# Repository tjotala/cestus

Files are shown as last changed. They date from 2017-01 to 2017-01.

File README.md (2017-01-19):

# Cestus

## Introduction

This is a software & hardware project for an automatic orientation-controlled turn & stop light mounted on bicycle gloves. Hence, the name [___cestus___](https://en.wikipedia.org/wiki/Cestus): the Latin word for a ___battle glove___ used by boxers and gladiators of ancient Greece and Rome. Seems appropriate, given how dangerous it can be to share the road in the U.S.

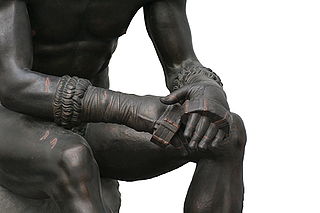
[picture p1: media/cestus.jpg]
cestus


## Hardware Parts

| Part | Cost |
| ---- | ---: |
| [Adafruit Flora v3](https://www.adafruit.com/product/659) system board | $14.95 |
| [Adafruit LSM9DS0](https://www.adafruit.com/products/2020) sensor board | $19.95 |
| [Adafruit NeoPixel Ring 16](https://www.adafruit.com/products/1463) multicolor LEDs | $9.95 |
| [Adafruit LiPoly 150mAh Battery](https://www.adafruit.com/products/1317) | $5.95 |
| **TOTAL** | **$50.80** |

In addition, you'll need a bicycle glove (or really any glove) and some [1&frac12;" diameter clear heat shrink tubing](http://www.frys.com/product/3222541). When flattened, the heat shrink tubing is about 2" wide and fits nicely around the Flora board stacked with the NeoPixel ring.

Note that these only make up one __cestus__ glove. If you build two, they operate independently of each other. While this is perhaps not the most cost-effective option, it wasn't a huge concern for me.

Some alternatives to consider for a more cost-effective solution:

* I used the Adafruit Flora system board even though a less powerful (and smaller) system board would suffice: for example, [Adafruit Gemma v2](https://www.adafruit.com/product/1222). The challenge is that doing so would require substantial re-factoring of the stock Adafruit libraries, in particular trading off flexibility and portability in favor of reduced code size. Gemma has only about 5KB of code space, and the project as currently written compiles to about 15.5KB (Flora has about 28.5KB available). Additionally, Gemma (based on ATtiny85) is not officially supported by the [LSM9DS0 sensor library](https://github.com/adafruit/Adafruit_LSM9DS0_Library) though I believe it ought to work.
* I used the Adafruit LSM9DS0 sensor board even though it was a complete overkill as I really only needed the accelerometer for this project. You could use one of the cheaper sensors with less features: for example, [Adafruit LSM303](https://www.adafruit.com/products/1247) or [Adafruit LIS3DH](https://www.adafruit.com/products/2809).

## Hardware Assembly

The hardware wiring is pretty straightforward, as illustrated below. You could use another pin instead of `D6` for the NeoPixel ring, but doing so will require changing the `CONF_NEOPIXEL_PIN` constant in the code.

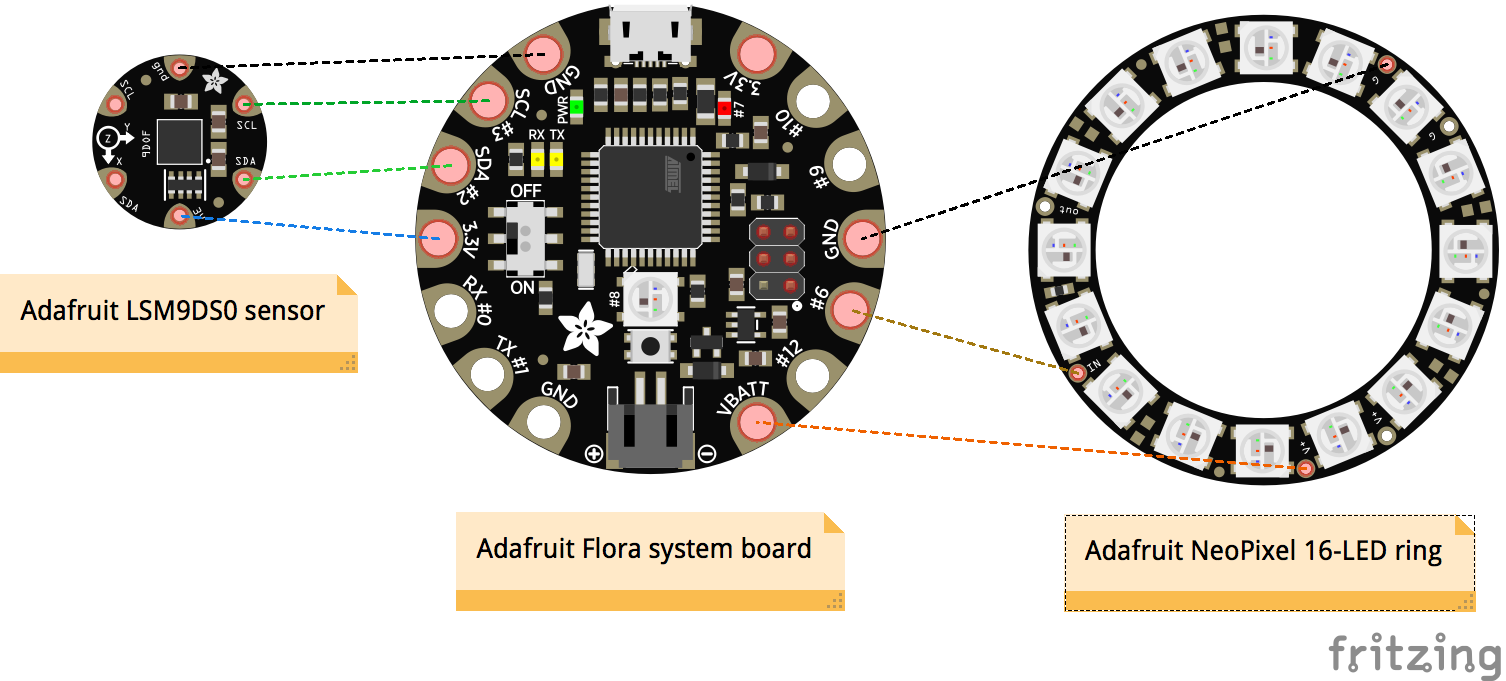
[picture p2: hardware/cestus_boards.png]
Boards


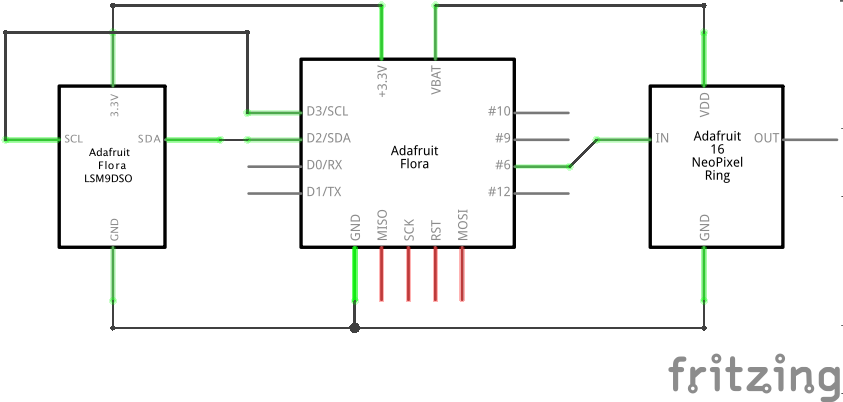
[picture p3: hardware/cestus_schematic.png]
Schematic


## Software Pre-requisites

You will need to install the [Arduino IDE](https://learn.adafruit.com/adafruit-arduino-ide-setup/arduino-1-dot-6-x-ide) or equivalent development environment. In addition, you will need to install the following Arduino libraries:

1. [Adafruit Unified Sensor Library](https://github.com/adafruit/Adafruit_Sensor)
2. [Adafruit LSM9DS0 Sensor Library](https://github.com/adafruit/Adafruit_LSM9DS0_Library)
3. [Adafruit AHRS (Altitude and Heading Reference System) Library](https://github.com/adafruit/Adafruit_AHRS)
4. [Adafruit NeoPixel library](https://github.com/adafruit/Adafruit_NeoPixel)
5. [NeoPatterns library](https://github.com/tjotala/NeoPatterns) which I adapted from the original [Adafruit NeoPatterns](https://learn.adafruit.com/multi-tasking-the-arduino-part-3/using-neopatterns) library to better suit my needs and enable easier enhancements. The original library is not in GitHub, otherwise I would have forked it.

## Building the Software

1. Download the [code](https://github.com/tjotala/Cestus) -or- clone the repo: `git clone https://github.com/tjotala/Cestus.git`
2. Launch the Arduino IDE
3. Open the sketch: `File` -> `Open...`
3. Build the code: `Sketch` -> `Verify/Compile`

## Uploading Code to the Device

1. Connect the device to a free USB port
2. Configure the Arduino IDE for Flora using the `Tools` menu:
   1. Under `Board`, select `Arduino Flora`
   2. Under `Port`, select the appropriate USB port (on a Mac, it is named something like `/dev/cu.usbmodemNNN`)
3. Upload the code: `Sketch` -> `Upload`

## Operation

Once the device is powered ON, it will respond to the following motions from the level orientation - that is, if your gloved hand is flat on a table with the palm down.

1. Tilt the device **sideways** in either direction (i.e. 90&deg; from level), and it will animate a turn signal consisting of a _scanner_ pattern of red LEDs. This is similar to the back-and-forth swoosh of the [Knight Rider car](https://www.youtube.com/watch?v=54O_1mOab4Y), or the [Cylon warrior "eye"](https://www.youtube.com/watch?v=0ccKPSVQcFk) from Battlestar Galactica.
2. Tilt the device **straight up** (i.e. 90&deg; upward from level), and it will animate a stop signal consisting of red LEDs being turned alternatively ON and OFF (apparently known as _theater chase_ pattern).
3. Tilt the device **straight down** (i.e. 90&deg; downward from level), and it will animate a go signal consisting of white LEDs pulsating ON and OFF (I coined the name _pulsar_ pattern).

## Tweaking the Software

1. The `CONF_USE_DEBUG_OUTPUT` and `CONF_DEBUG_OUTPUT_SPEED` constants control whether to send debug output messages to the host Mac/PC over serial connection, and how fast to do it. Turning this OFF (the default) saves couple of KB of code space.
2. The `CONF_BLINK_ONBOARD_LED` constant controls whether to blink the on-board LED each time the code samples the orientation sensor. Given that the LED is on the underside of the device, this is purely for debugging purposes.
3. The `CONF_TURN_xxx` constants control the orientation tolerance, timing, colors, etc. of the turn signal.
4. The `CONF_STOP_xxx` constants control the orientation tolerance, timing, colors, etc. of the stop signal.
5. The `CONF_GO_xxx` constants control the orientation tolerance, timing, colors, etc. of the go signal.
6. The `CONF_ONBOARD_LED_PIN` constant defines which digital pin connects to the on-board LED. On the Flora board, this is always 7.
7. The `CONF_ONBOARD_NEOPIXEL_PIN` constant defines which digital pin connects to the on-board NeoPixel LED. On the Flora board, this is always 8.
8. The `CONF_NEOPIXEL_PIN` constant defines which digital ping connects to the NeoPixel ring, and the `CONF_NEOPIXEL_LEDS` constant defines how many LEDs there are in the NeoPixel ring/strip.

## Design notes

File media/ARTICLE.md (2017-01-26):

# I Have Seen The Light... and It Is Smarter

Something has always bothered me about bicycle lights: they are fundamentally dumb. No, I do not mean that they are useless - but rather how they are not adaptive to our riding behavior. There is no way to indicate intent as we do with the turn signals and brake lights in a car.

## Solution

A while back I decided to solve this problem when I resumed bicycling for exercise. I named the solution [___cestus___](https://en.wikipedia.org/wiki/Cestus), after the Latin word for an armored ___battle glove___ used by boxers and gladiators of ancient Greece and Rome. It seemed only appropriate given how dangerous it can be to share the road in the U.S.

cestus

credit: [wikimedia](https://upload.wikimedia.org/wikipedia/commons/thumb/7/70/Boxer_of_quirinal_hands.jpg/320px-Boxer_of_quirinal_hands.jpg)

The idea is to attach this smarter bicycle light to the back of hand of a regular biking glove, and do what feels fairly natural:

* When I extend my arm to the left or right with the palm facing forward, it animates a red turn signal.
* When I extend my arm straight up, it flashes all the LEDs as a red stop signal.
* When I extend my arm down or simply tilt my wrist down, it turns into a flashing bright white headlight.

The tolerance for those positions is fairly loose, &plusmn;30&deg; from the 90&deg; orientation, to accommodate sloppy signaling.

The videos below illustrate this much better than my words.

### Turn Signal
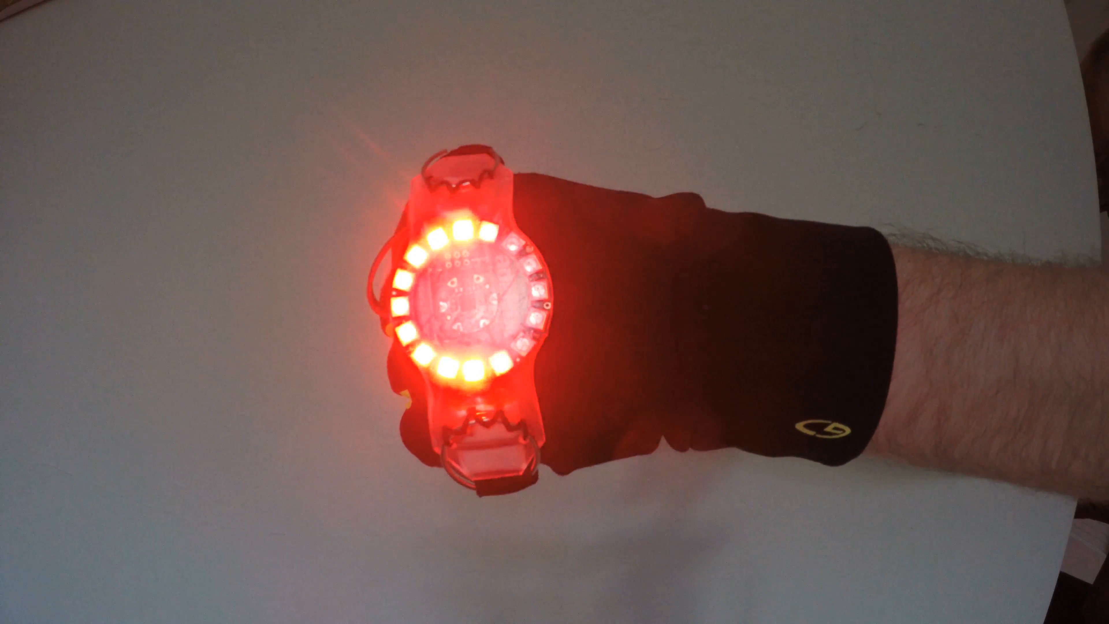
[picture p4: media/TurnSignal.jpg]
Turn Signal


### Stop Signal
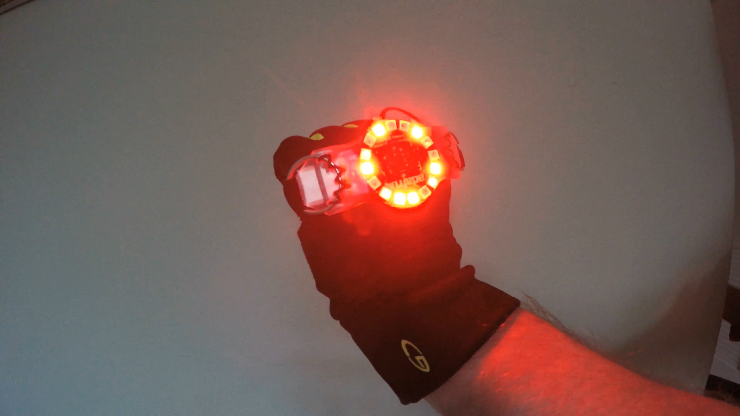
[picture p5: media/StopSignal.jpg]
Stop Signal


### Headlight
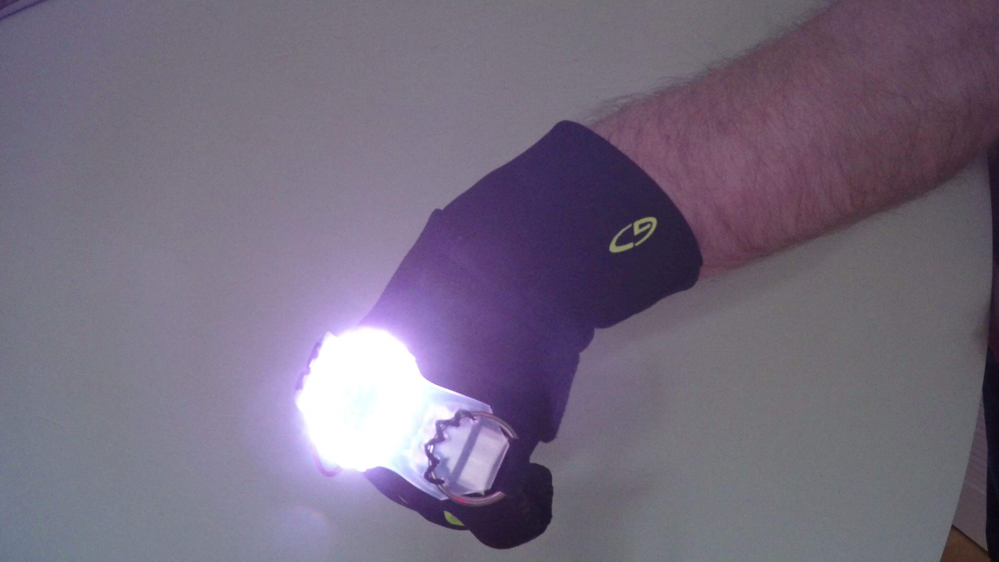
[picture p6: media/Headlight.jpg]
Headlight


## Hardware

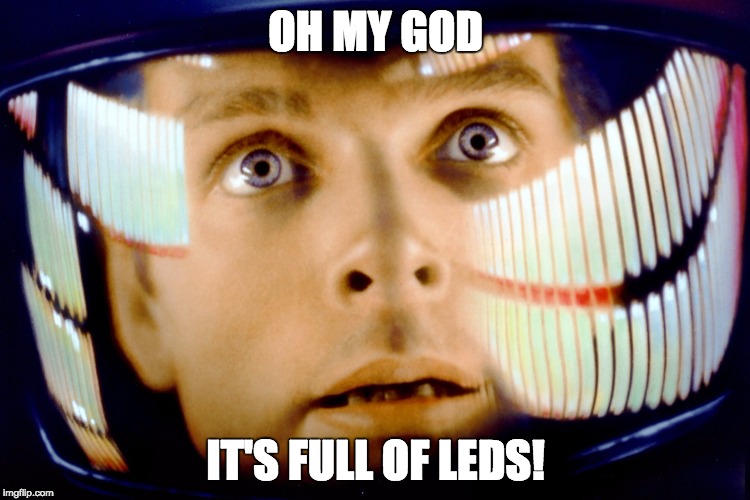
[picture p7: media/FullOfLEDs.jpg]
Full of LEDs


The proof-of-concept system consists of four components developed by [Adafruit] for wearable designs:

1. An [Arduino]-compatible system board
2. A sensor board
3. A highly visible ring of 16 multicolor LEDs
3. A small rechargeable LiPoly battery

The total cost of the parts is around $50, and with one charge of the battery it runs for about 30-60 minutes depending on usage. I could have used a higher capacity battery but my bicycle rides are simply not long enough to justify it.

If I were to productize this solution, I could substantially reduce the cost with less expensive parts and tighter system integration. Unlike it's ancient name sake, I chose not to encase it in armor or leather due to both weight and cost considerations. I thought of 3D printing a case for the light, but ultimately simply wrapped it in clear heat shrink tubing to protect it from the elements. In addition, I chose to mount the device on a neoprene strap that I can then slip over my hand, rather than sew it directly onto the back of the glove. This has the added benefit of being able to use it without a glove, like in the middle of scorching California summer, and makes it easier to wash the gloves.

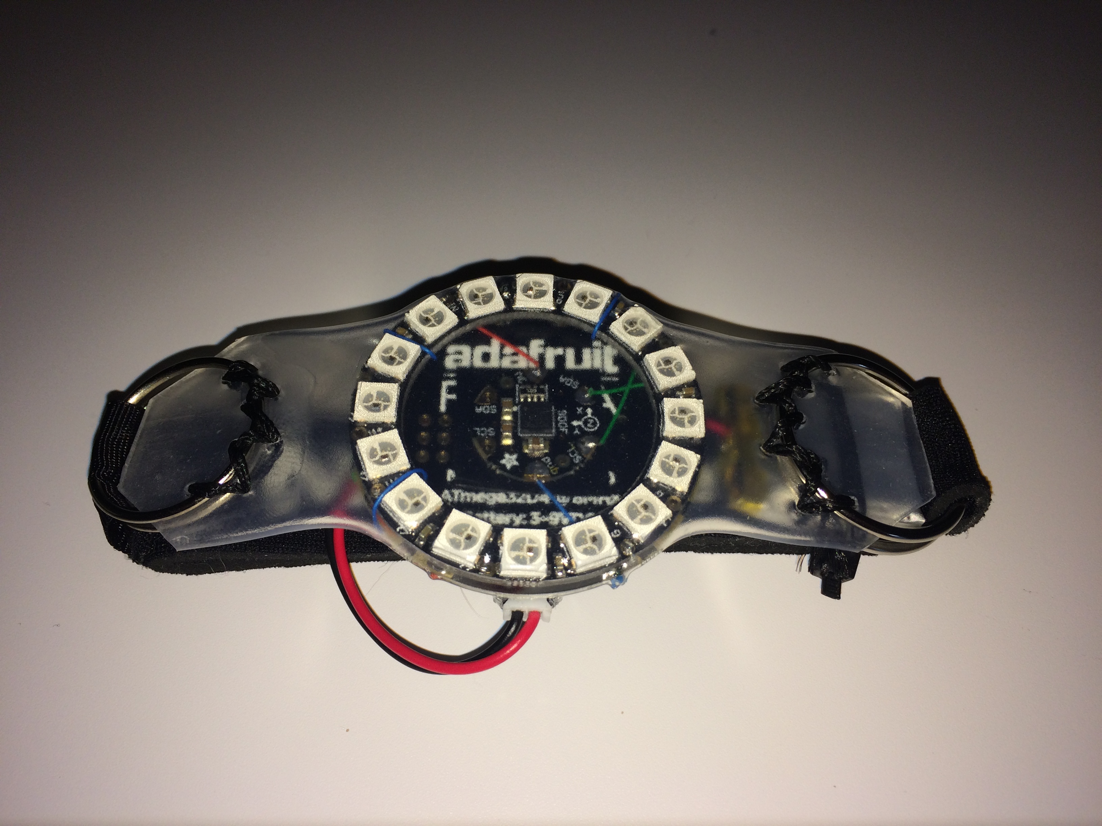
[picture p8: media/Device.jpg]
Device


## Software

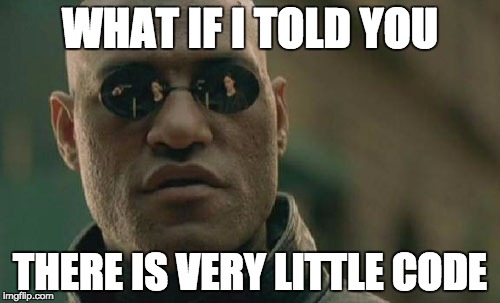
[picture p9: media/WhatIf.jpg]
What If I Told You


The software is very simple: there's only about 100 lines of actual C++ code, aside from existing [Adafruit] libraries. As with any [Arduino] application, there are two functions:

* The `setup` function is called at power on exactly once to initialize everything
* The `loop` function gets called repeatedly until power off. It samples the orientation sensor in the beginning of each iteration, and then switches between four possible states:

	1. Begin animating a new signal
	2. Continue animating a previously chosen signal
	3. Stop animating a signal
	4. Do nothing

## Technical Details

The source code and wiring diagrams are freely available in a [github][repo] repository under MIT license. If you are interested in more technical details, check out the [README][repo].

## Conclusion

This was a fun little project. As usual for me, the software was simple and the toughest part was figuring out how to package the hardware in a way that is easy to use, easy to attach to a glove, and robust enough to handle the harsh California weather. Why, we sometimes even get rain around here!

## Enhancement Ideas

The sensor board I used can also measure acceleration, compass heading and temperature. I only needed the orientation for this project as currently implemented. I was tempted to automatically turn on the stop signal automatically based on sudden deceleration. I thought of making the ring LED briefly show a heading indicator if flicked in a certain way, or perhaps do something cute with the temperature data. I could also make something like interval timer or elapsed time by turning on sections of the LEDs.

Ultimately I decided against all those ideas, because of their limited utility. Without moving your hand, automating the stop signal would not be visible to anyone behind you. As for the compass heading indicator or temperature, I simply did not see much utility in them. I do not bike far enough for the heading to matter, and my skin can readily tell if it is cold or hot. The timer features might come in handy but then most of the time I bike with a smartphone that acts as GPS tracker so I have no need for additional clock sources.

Speaking of GPS, it would be fairly easy to add a GPS receiver to this device as well, but that would substantially increase the cost and power consumption, not to mention create further problems with where to store the location data and how to offload it. In short, it creates more problems than it solves: a classic case of "just because we can, we should not". Put another way, don't draw legs on the snake as the Chinese proverb goes.

[Arduino]: https://www.arduino.cc/
[Adafruit]: https://www.adafruit.com/
[repo]: https://github.com/tjotala/cestus

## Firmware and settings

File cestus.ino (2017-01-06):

//
// Cestus
//
// Copyright (c) 2016-2017 Tapani J. Otala
//
// See README.md for details on the source code.
// See LICENSE for details on license.
//
#include <Adafruit_LSM9DS0.h>
#include <Adafruit_Simple_AHRS.h>
#include <Adafruit_NeoPixel.h>
#include <NeoPatterns.h>

// common colors
#define COLOR(r, g, b)              Adafruit_NeoPixel::Color(r, g, b)
#define COLOR_BLACK                 COLOR(0, 0, 0)
#define COLOR_WHITE                 COLOR(255, 255, 255)
#define COLOR_RED                   COLOR(255, 0, 0)
#define COLOR_GREEN                 COLOR(0, 255, 0)
#define COLOR_BLUE                  COLOR(0, 0, 255)

// brightness setting 0..255 from percentage 0..100%
#define BRIGHTNESS(b)               uint8_t((b) != 0 ? 255 * 100 / (b) : 0) 

// configuration settings
#define CONF_USE_DEBUG_OUTPUT       false         // true: enable, false: disable
#define CONF_DEBUG_OUTPUT_SPEED     115200        // bps

#define CONF_BLINK_ONBOARD_LED      50            // ms; set to 0 to not blink at all

#define CONF_TURN_TOLERANCE         30            // ± degrees; tolerance from 90deg roll (for turn signal)
#define CONF_TURN_INTERVAL          10            // ms
#define CONF_TURN_COLOR             COLOR_RED
#define CONF_TURN_BRIGHTNESS        BRIGHTNESS(50)
#define CONF_TURN_SPLIT             true          // true: split the pattern into two segments, false: unidirectional pattern

#define CONF_STOP_TOLERANCE         30            // ± degrees; tolerance from 90deg pitch (for stop signal)
#define CONF_STOP_INTERVAL          50            // ms
#define CONF_STOP_COLOR1            COLOR_RED
#define CONF_STOP_COLOR2            COLOR_BLACK
#define CONF_STOP_BRIGHTNESS        BRIGHTNESS(100)

#define CONF_GO_TOLERANCE           30            // ± degrees; tolerance from 90deg pitch (for ride signal)
#define CONF_GO_INTERVAL            100           // ms
#define CONF_GO_COLOR1              COLOR_WHITE
#define CONF_GO_COLOR2              COLOR_BLACK
#define CONF_GO_BRIGHTNESS          BRIGHTNESS(100)

// hardware constants for Adafruit Flora on-board resources
#define CONF_ONBOARD_LED_PIN        7             // hardwired
#define CONF_ONBOARD_NEOPIXEL_PIN   8             // hardwired

// hardware constants for the NeoPixel ring
#define CONF_NEOPIXEL_PIN           6             // connected to pin D6
#define CONF_NEOPIXEL_LEDS          16            // number of LEDs

#if CONF_USE_DEBUG_OUTPUT
#define DEBUG_OUT(msg)              Serial.print(msg)
#define DEBUG_OUTLN(msg)            Serial.println(msg)
#else
#define DEBUG_OUT(msg)              /* nothing */
#define DEBUG_OUTLN(msg)            /* nothing */
#endif

//
// Derived Classes
//
class TurnPattern : public Scanner
{
public:
    TurnPattern(NeoPatterns& pixels) : Scanner(pixels, CONF_TURN_INTERVAL, CONF_TURN_COLOR, CONF_TURN_SPLIT) { }
};

class StopPattern : public TheaterChase
{
public:
    StopPattern(NeoPatterns& pixels) : TheaterChase(pixels, CONF_STOP_INTERVAL, CONF_STOP_COLOR1, CONF_STOP_COLOR2) { }
};

class GoPattern : public Pulsar
{
public:
    GoPattern(NeoPatterns& pixels) : Pulsar(pixels, CONF_GO_INTERVAL, CONF_GO_COLOR1, CONF_GO_COLOR2) { }
};

//
// Global Variables
//
NeoPatterns ring(CONF_NEOPIXEL_LEDS, CONF_NEOPIXEL_PIN);
Adafruit_LSM9DS0 sensor;
Adafruit_Simple_AHRS ahrs(&sensor.getAccel(), &sensor.getMag());

//
// Setup function
//
// This executes exactly once, at startup
//
void setup()
{
#if CONF_USE_DEBUG_OUTPUT
    Serial.begin(CONF_DEBUG_OUTPUT_SPEED);
    DEBUG_OUTLN(F("Cestus v1.0"));
#endif

#if CONF_BLINK_ONBOARD_LED
    // initialize the on-board LED
    pinMode(CONF_ONBOARD_LED_PIN, OUTPUT);
#endif

    // initialize the sensor(s)
    // we really only need acceleration
    // however, the AHRS library expects magnetometer as well
    // we do not need the gyroscope or temperature
    sensor.setupAccel(sensor.LSM9DS0_ACCELRANGE_2G);
    sensor.setupMag(sensor.LSM9DS0_MAGGAIN_2GAUSS);
    if (!sensor.begin())
    {
#if CONF_USE_DEBUG_OUTPUT
        while (true)
        {
            DEBUG_OUTLN(F("Oops ... unable to initialize the LSM9DS0. Check your I2C wiring!"));
        }
#endif
    }

    // initialize the NeoPixel Ring
    ring.begin();
}

template<typename T> bool InRange(T val, T min, T max)
{
    return min <= val && val <= max;
}

//
// Loop
//
// This code runs continuously until powered off
//
void loop()
{
#if CONF_BLINK_ONBOARD_LED
    //
    // Blink the on-board LED
    //
    digitalWrite(CONF_ONBOARD_LED_PIN, HIGH);
    delay(CONF_BLINK_ONBOARD_LED);
    digitalWrite(CONF_ONBOARD_LED_PIN, LOW);
#endif
  
    //
    // Sample the current orientation
    //
    sensors_vec_t orientation;
    ahrs.getOrientation(&orientation);

    DEBUG_OUT(F("roll: ")); DEBUG_OUT(int(orientation.roll));
    DEBUG_OUT(F(", pitch: ")); DEBUG_OUT(int(orientation.pitch));
    DEBUG_OUT(F(", heading: ")); DEBUG_OUT(int(orientation.heading));
    DEBUG_OUTLN(F(""));

    //
    // Animate a stop signal if we're oriented at 90deg pitch angle, with ±CONF_STOP_TOLERANCE
    //
    if (InRange(int(orientation.pitch), 90 - CONF_STOP_TOLERANCE, 90 + CONF_STOP_TOLERANCE))
    {
        static StopPattern stop(ring);
        if (!ring.IsActive(&stop))
        {
            DEBUG_OUTLN(F("starting stop animation"));
            ring.setBrightness(CONF_STOP_BRIGHTNESS);
            ring.Start(&stop);
        }
    }
    //
    // Animate a go signal if we're oriented at -90deg pitch angle, with ±CONF_GO_TOLERANCE
    //
    else if (InRange(int(orientation.pitch), -90 - CONF_GO_TOLERANCE, -90 + CONF_GO_TOLERANCE))
    {
        static GoPattern go(ring);
        if (!ring.IsActive(&go))
        {
            DEBUG_OUTLN(F("starting go animation"));
            ring.setBrightness(CONF_GO_BRIGHTNESS);
            ring.Start(&go);
        }
    }
    //
    // Animate a turning signal if we're oriented at 90deg or -90deg roll angles, with ±CONF_TURN_TOLERANCE
    //
    else if (InRange(int(orientation.roll), 90 - CONF_TURN_TOLERANCE, 90 + CONF_TURN_TOLERANCE) ||
             InRange(int(orientation.roll), -90 - CONF_TURN_TOLERANCE, -90 + CONF_TURN_TOLERANCE))
    {
        static TurnPattern turn(ring);
        if (!ring.IsActive(&turn))
        {
            DEBUG_OUTLN(F("starting turn animation"));
            ring.setBrightness(CONF_TURN_BRIGHTNESS);
            ring.Start(&turn);
        }
    }
    else
    {
        ring.Stop();
    }
    ring.Update();
}
